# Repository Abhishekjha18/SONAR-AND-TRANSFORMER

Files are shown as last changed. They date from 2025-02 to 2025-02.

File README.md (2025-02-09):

# SONAR-AND-TRANSFORMER
# Transformer & SONAR Project

This repository contains the design, simulation, fabrication, and testing of two analog circuit modules:
- **SONAR Module:** A narrowband ultrasonic Doppler sensor for motion detection.
- **Transformer Module:** Analog transformer circuits incorporating filters and voltage regulators for stable power delivery.

---

## SONAR Module

**Description:**
- Designed, simulated, fabricated, and tested a narrowband ultrasonic Doppler sensor for motion detection.
- Integrated transmitter and receiver circuits with ultrasonic sensors to enable accurate distance measurement.
- PCB layout was executed using **EagleCAD**.

**Key Technologies:**
- **LTSpice** for circuit simulation.
- **EagleCAD** for PCB design.
- Analog circuit design principles for sensor integration.
- **CIRCUITS THAT HELPED IN THE SONAR:**
Screenshot 2025-02-09 at 3 48 58 PM
Screenshot 2025-02-09 at 3 49 10 PM
Screenshot 2025-02-09 at 3 49 34 PM
Screenshot 2025-02-09 at 3 49 40 PM
Screenshot 2025-02-09 at 3 49 48 PM
Screenshot 2025-02-09 at 3 50 22 PM
Screenshot 2025-02-09 at 3 50 44 PM
Screenshot 2025-02-09 at 3 50 54 PM

---

## Transformer Module

**Description:**
- Developed analog transformer circuits that include essential filters and voltage regulators for reliable power delivery.
- Designed, simulated, fabricated, and tested the circuits to ensure stable performance under varying conditions.
- PCB layout was implemented using **KiCad**.

**Key Technologies:**
- **LTSpice** for circuit simulation.
- **KiCad** for PCB design.
- Analog circuit design best practices for power regulation.
- **CIRCUITS THAT HELPED IN THE TRANSFORMER:**
Screenshot 2025-02-09 at 3 33 59 PM
Screenshot 2025-02-09 at 3 34 11 PM
Screenshot 2025-02-09 at 3 34 26 PM
Screenshot 2025-02-09 at 3 34 42 PM
Screenshot 2025-02-09 at 3 34 48 PM
Screenshot 2025-02-09 at 3 34 52 PM
Screenshot 2025-02-09 at 3 35 03 PM

---

## Tools & Technologies

- **LTSpice:** Circuit simulation
- **EagleCAD:** PCB design for the SONAR module
- **KiCad:** PCB design for the Transformer module
- **Analog Circuit Design:** Implementation of filters, voltage regulators, rectifiers and sensor circuits

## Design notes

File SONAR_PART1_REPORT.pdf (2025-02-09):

INDRAPRASTHA INSTITUTE of
INFORMATION TECHNOLOGY
DELHI

### Department

of

### Electronics & Communication Engineering

Circuit Theory and Devices

Dr. Shobha Sundar Ram

### Lab_2: LPF and BPF design in LTSpice

## Student Name: Abhishek Jha Roll No. : 2022023 Date: 18 August 2023

### Objective:

1. Design first, and second order Low Pass and Band Pass filters using RC circuits on the software Ltspice.
2. Plot the magnitude and phase response of the filters in a Bode plot and compare their performances.
2 | Page

Theoretical Calculations:

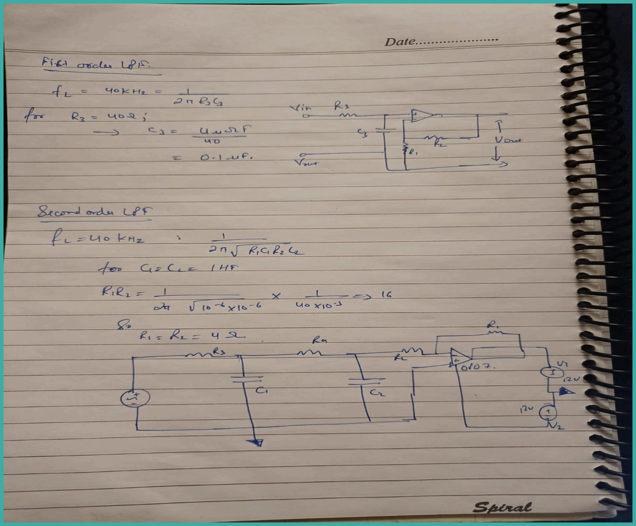
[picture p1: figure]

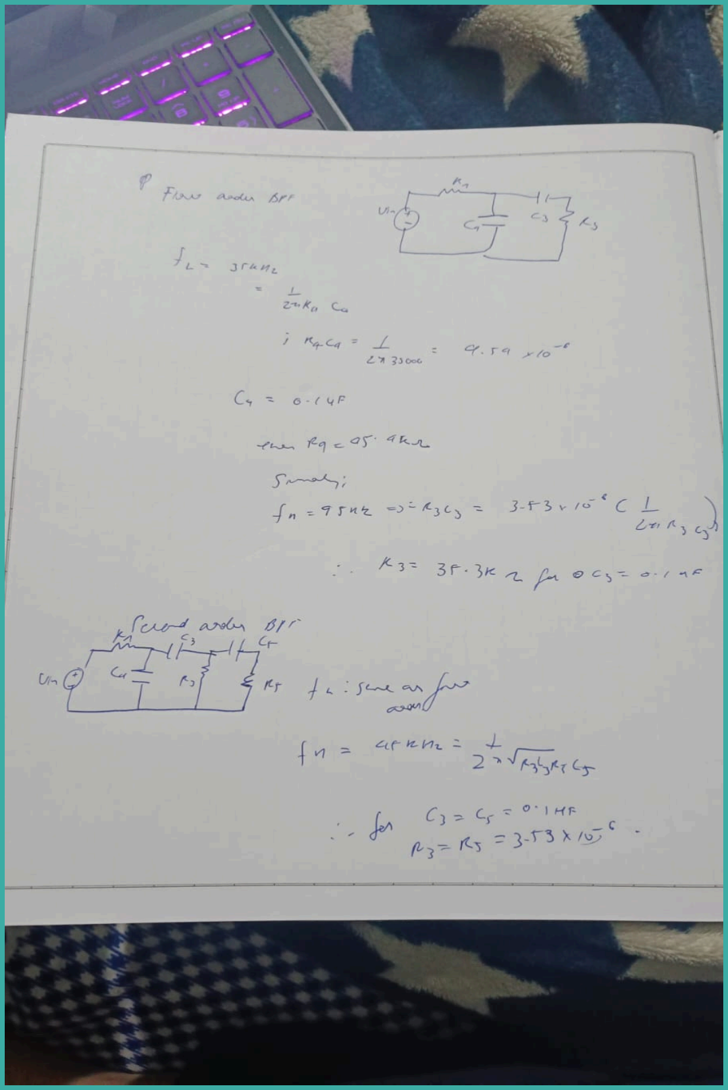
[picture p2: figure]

Observations:

1) LOW PASS FILTER -:
- All signals over a certain frequency are muted in a low pass filter. The signals are attenuated after they reach the cutoff frequency (fH), and after a specific higher frequency, they are entirely suppressed.
- The roll-off rate for the first order LPF is -20 dB/decade, as would be

expected for a single-order filter.
- Except for the fact that the gain will be twice as steep at 40dB/decade as the first order filter, the second order low pass filter's frequency response is identical to that of the first order version.
- The roll-off rate for the second order LPF is -40 dB/decade, as would be expected for a two-order filter. Compared to the first order filter, the change from the passband to the stopband is sharper.

BAND PASS FILTER-:

- The bandwidth for the first order BPF is determined by the lower and upper cutoff frequencies.
- Only signals within the chosen frequency range are permitted to exit the band pass filter; all other signals are blocked.While signals from other frequencies are attenuated, transmissions in the frequency range of fL to fH are allowed to flow through the filter.

- The lower cutoff frequency for the second order BPF is the same as the first order. In comparison to 1st order, the higher cutoff frequency shifts based on the cascaded LPF sections, providing a sharper transition between the passband and stopband.
- A higher order filter offers sharper attenuations beyond the pass band compared to a lower order, with the peak frequency of the first order in a band pass filter being higher than the peak frequency of the second order (the order of a filter is defined by the number of storage elements (capacitors and inductors)).

Plots:

1st order lpf

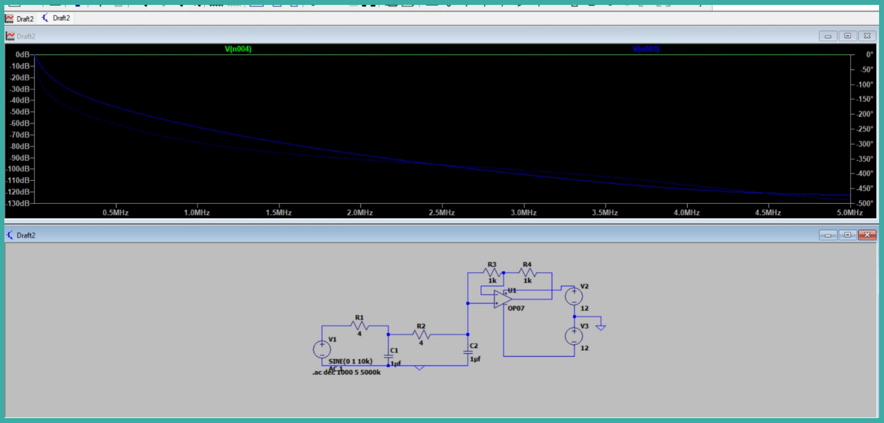
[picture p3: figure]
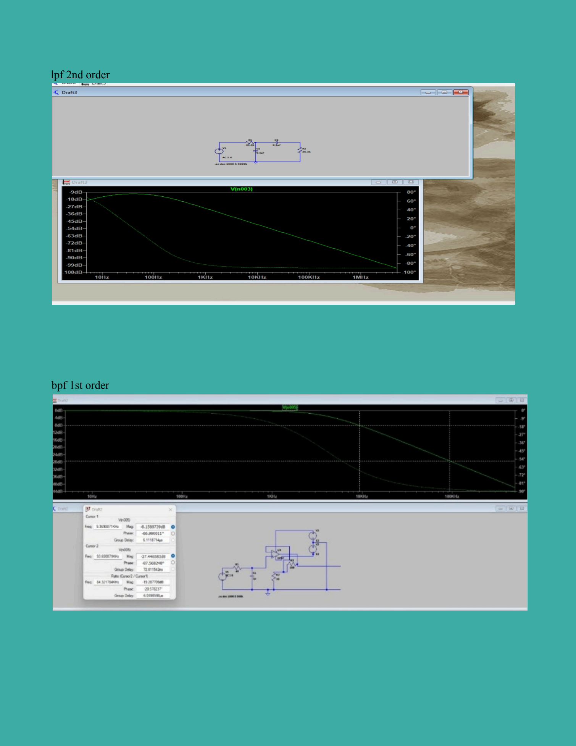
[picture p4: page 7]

lpf 2nd order

bpf 1st order

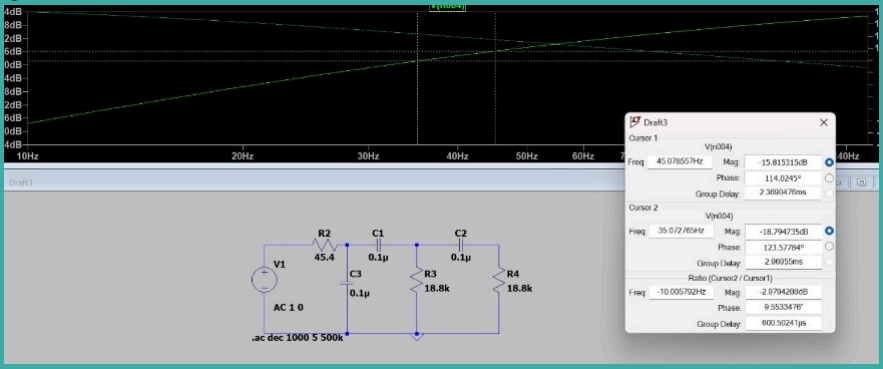
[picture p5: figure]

bpf 2nd order

Conclusions:
An essential device in electronics is a low pass filter, which attenuates higher frequencies while allowing signals below a particular threshold to flow through. It is indispensable in a wide range of applications due to its capacity to filter out undesirable noise and high-frequency components. Low-pass filters are a key element in a world where precise signal handling is necessary.
A frequency selective filter circuit called an active band pass filter is used in electronic systems to distinguish between signals at a single frequency or a range of frequencies that fall within a defined "band" from signals at all other frequencies.This band or frequency range is situated between two corner or cutoff frequencies known as the "lower

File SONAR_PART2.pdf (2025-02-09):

### INDRAPRASTHA INSTITUTE of INFORMATION TECHNOLOGY DELHI

Department
of
Electronics & Communication Engineering

Circuit Theory and Devices

Dr. Shobha Sundar Ram

## Lab 3: Prototype Design of a SONAR Transmitter

Date: 02/09/2023
Submitted by:-
Group 12
Abhishek Jha (2022023)
Mann sharma (2022279)
Mayank Kumar kankheria(2022286)

### OBJECTIVE:

The objective of this lab assignments is to learn how to
a. Read a datasheet for finding out the key information relevant to a design.
b. Develop a prototype of a Sonar transmitter on a breadboard and test its desired outcome.
2 | Page

## Theoretical Calculations:

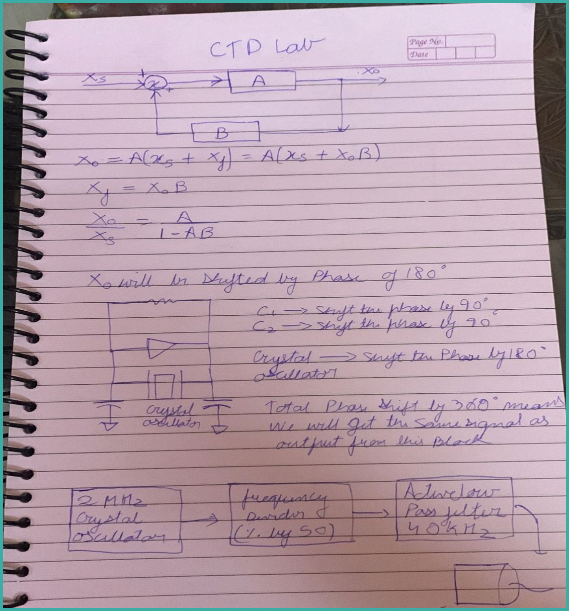
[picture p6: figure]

### Observations:

- FOR TP1-A 2MHz oscillating signal is present at TP1.
- FOR TP2-By using the IC4017 and dividing 2MHz by 10, the oscillating signal at TP2 has a frequency of 200 KHz.
- FOR TP3-By dividing 200 kHz by 5, the oscillating signal at TP3 is at a frequency of 40 kHz. The signal is divided by the frequency divider from 2MHz to 40KHz overall.
An active low pass filter is used to pass the signal from TP3 through. 40KHz is the filter cutoff frequency.
- FOR TP4-The FFT capability of DSO is used to check the frequency information of the signal from TP4; the frequency with the largest peak is at Delta(X)=4us with a span of 1MHz.

## Following are the respective plotsn we got on DSO:-

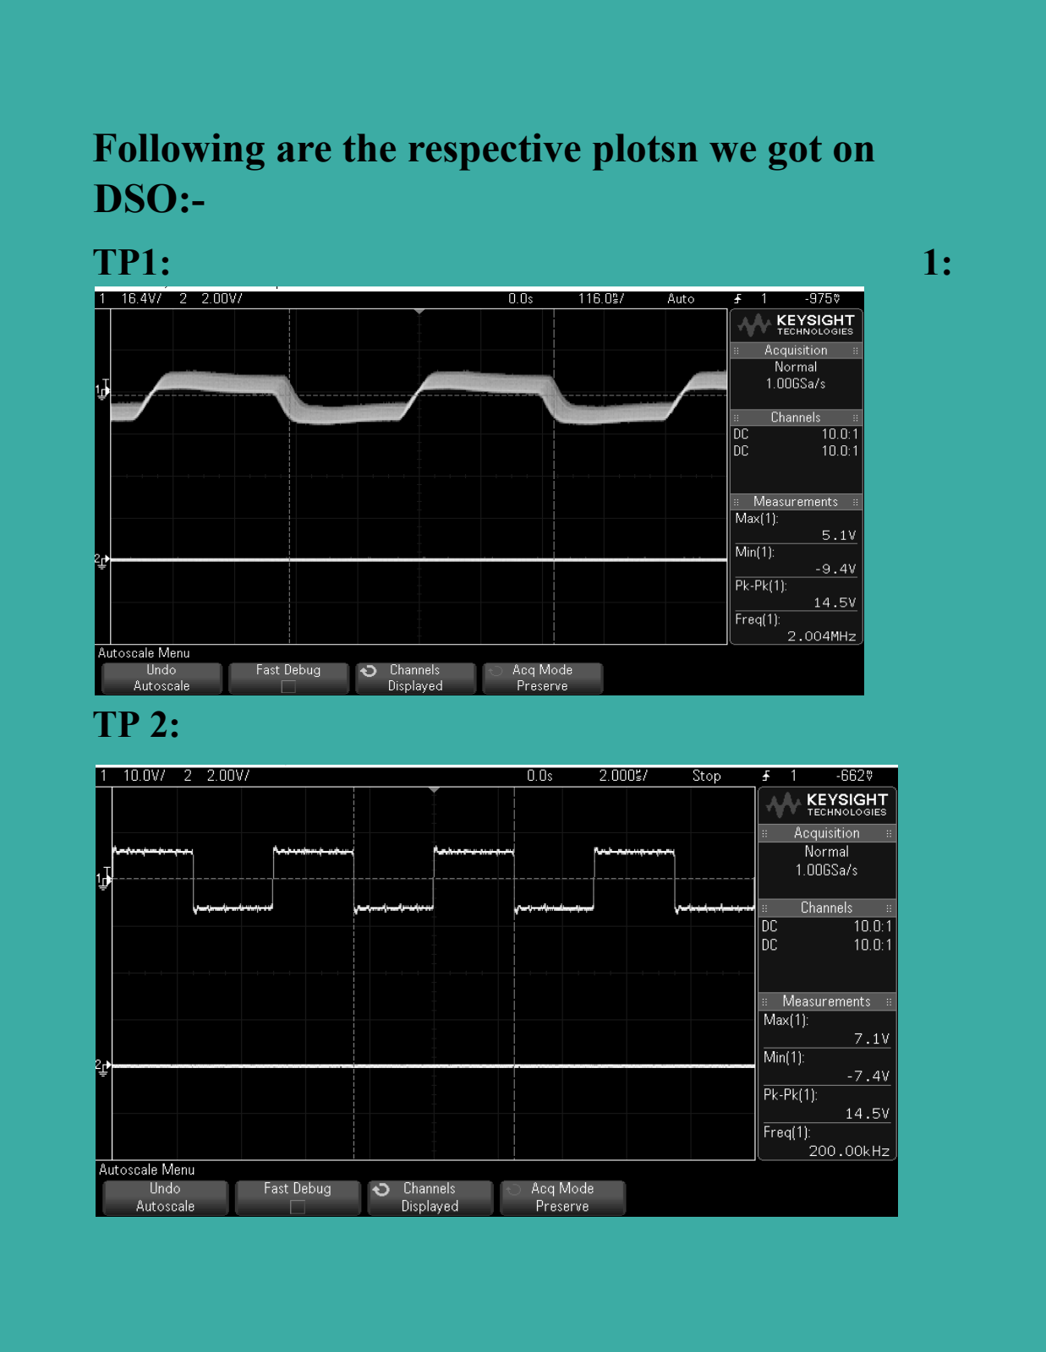
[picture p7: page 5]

TP1: | 1:

TP 2:

TP 3:

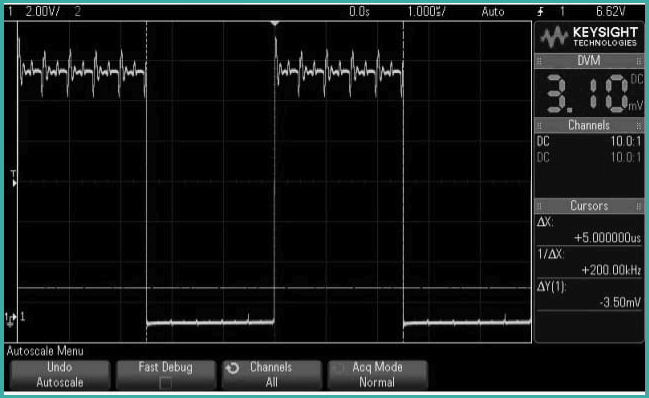
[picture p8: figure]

TP 4:

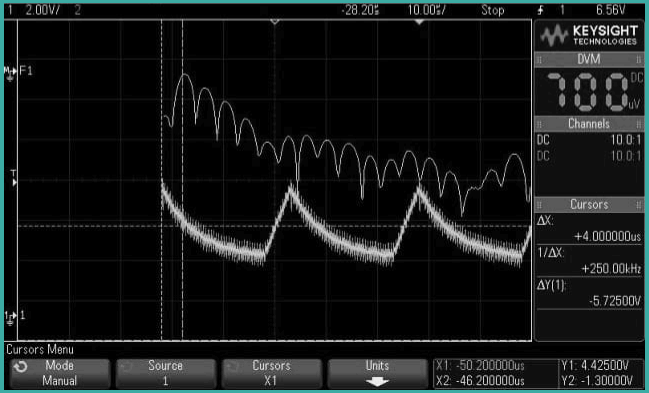
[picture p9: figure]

### Conclusions:

The transmitter utilizes a crystal oscillator to generate a sinusoidal wave with a frequency of 2MHz. This 2MHz input signal is then subjected to a frequency division process, resulting in a 40KHz (f o) output signal achieved by dividing it by a factor of 50. To ensure the elimination of any higher order harmonics, a low pass filter is employed.

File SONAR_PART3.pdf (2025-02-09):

INDRAPRASTHA INSTITUTE of
INFORMATION TECHNOLOGY
DELHI

Department
of
Electronics & Communication Engineering

Circuit Theory and Devices

Dr. Shobha Sundar Ram

## Lab_5: Prototype design of a SONAR receiver

Date: 06/10/2023

### Submitted by:-Group 12 Abhishek Jha (2022023) Mann sharma (2022279) Mayank Kumar kankheria(2022286)

Objective:

a.To develop a prototype of a SONAR receiver on a breadboard and test its desired outcome.
b.With SONAR Tx and Rx, observe the Doppler shift in the received
signal from a moving metal target.

Theoretical Calculations:

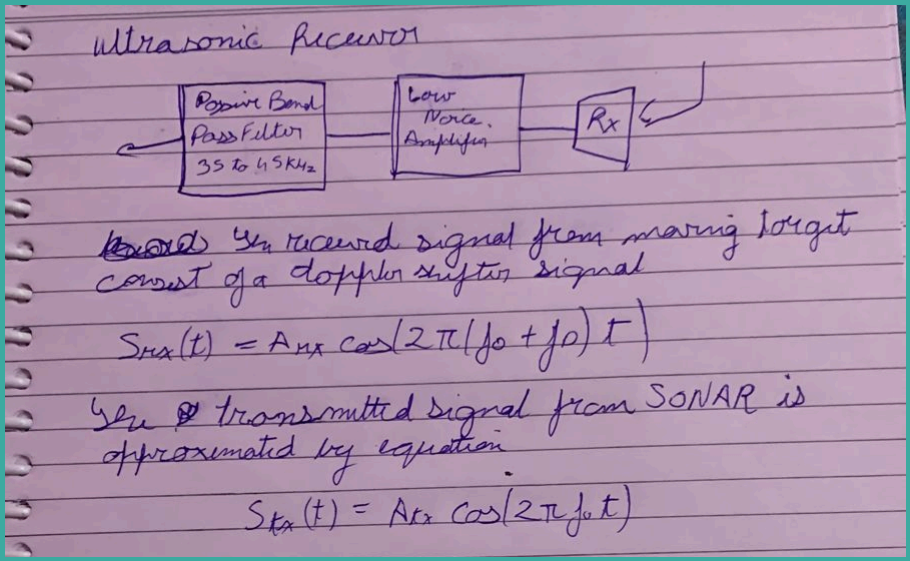
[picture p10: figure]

2 | Page

Observations:

1. The output signal frequency of the LNA at TP1 was detected, which we knew would be somewhat amplified, and the output was observed to be 42Khz at the TP1 point. We created a low noise amplifier and provided 40Khz from the DSO to the LNA.
2. We knew that by passing the output through BPF after that, the frequency would be reduced.
3. We then had our whole receiving circuit.
4. (Lab 3)The transmitter circuit underwent some modifications, the first of which was a shift in the crystal oscillator frequency from 2 Mhz to 4 Mhz. The signal frequency at TP1 was then determined to be 400Khz (4Mhz/10) using IC 4017, and at TP2 it was discovered to be 40Khz (4Mhz/10).
5. Then, a transducer was attached to the transmitter circuit, and its 40 kHz frequency was output.It was passed on the rotating motor and then it was reflected to the receiving transducer of the receiver circuit.
6. The final frequency was observed to be nearly 50Khz.

## Plots:

Transmitter circuit plots:
Signal frequency after division of 400KHz by 10 →

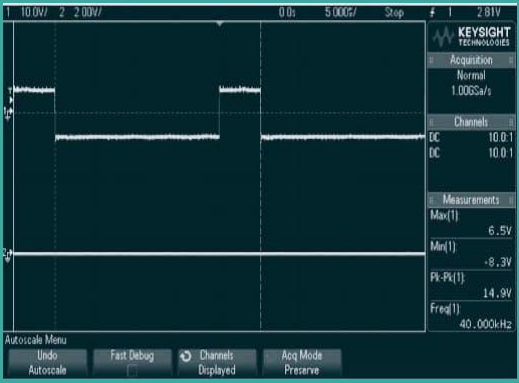
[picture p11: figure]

Signal frequency after passing the signal through the active low pass filter→

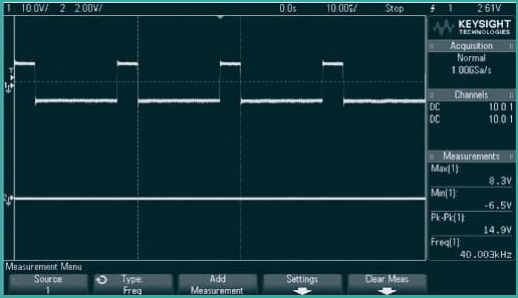
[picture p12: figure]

Conclusions:
1. (Arx <Atx) The transmitted signal is substantially stronger than the received signal. In order to increase the voltage, the signal is therefore sent via a low noise amplifier.
2. To eliminate higher order harmonics and restrict outside interference, band pass filters are used.
3. When a metal target travels ahead of the sonar, the frequency of the received signal should exhibit a Doppler shift starting at 40 KHz since the doppler effect results in a shift equal to 1/r4 the original frequency.

6 | Page

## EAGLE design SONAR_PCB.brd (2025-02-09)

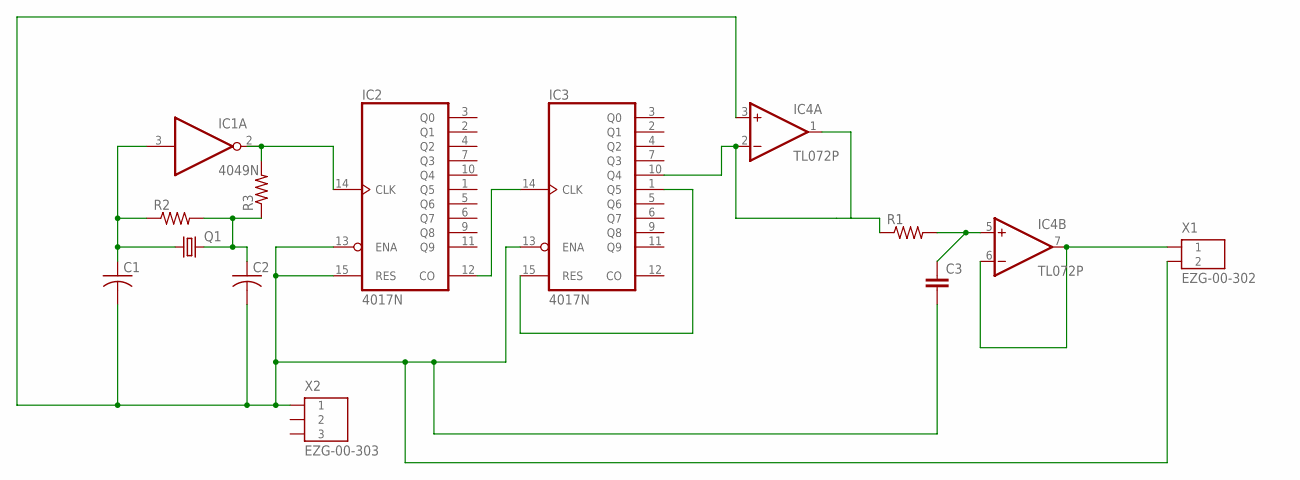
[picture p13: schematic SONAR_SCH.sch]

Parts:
C1, C2: C-US050-025X075; C050-025X075
C3: C2.5/2; C2.5-2
IC1: 4049N; DIL16
IC2, IC3: 4017N; DIL16
IC4: TL072P; DIL08
Q1: CRYSTALHC49U-V; HC49U-V
R1, R2, R3: R-US_0207/10; 0207/10
X1: EZG-00-302
X2: EZG-00-303

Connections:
unnamed: C1.1, IC1.3 (I), Q1.1, R2.1
unnamed: IC1.2 (O), IC2.14 (CLK), R3.2
unnamed: IC2.12 (CO), IC3.14 (CLK)
unnamed: IC3.10 (Q4), IC4.1 (OUT), IC4.2 (-IN), R1.1
unnamed: IC3.1 (Q5), IC3.15 (RES)
unnamed: C3.1, IC4.5 (+IN), R1.2
unnamed: IC4.6 (-IN), IC4.7 (OUT), X1.1
unnamed: C1.2, C2.2, C3.2, IC2.13 (ENA), IC2.15 (RES), IC3.13 (ENA), IC4.3 (+IN), X1.2, X2.1
unnamed: C2.1, Q1.2, R2.2, R3.1
V+: IC4.8 (V+)
V-: IC4.4 (V-)
VDD: IC1.1 (VDD), IC2.16 (VDD), IC3.16 (VDD)
VSS: IC1.8 (VSS), IC2.8 (VSS), IC3.8 (VSS)

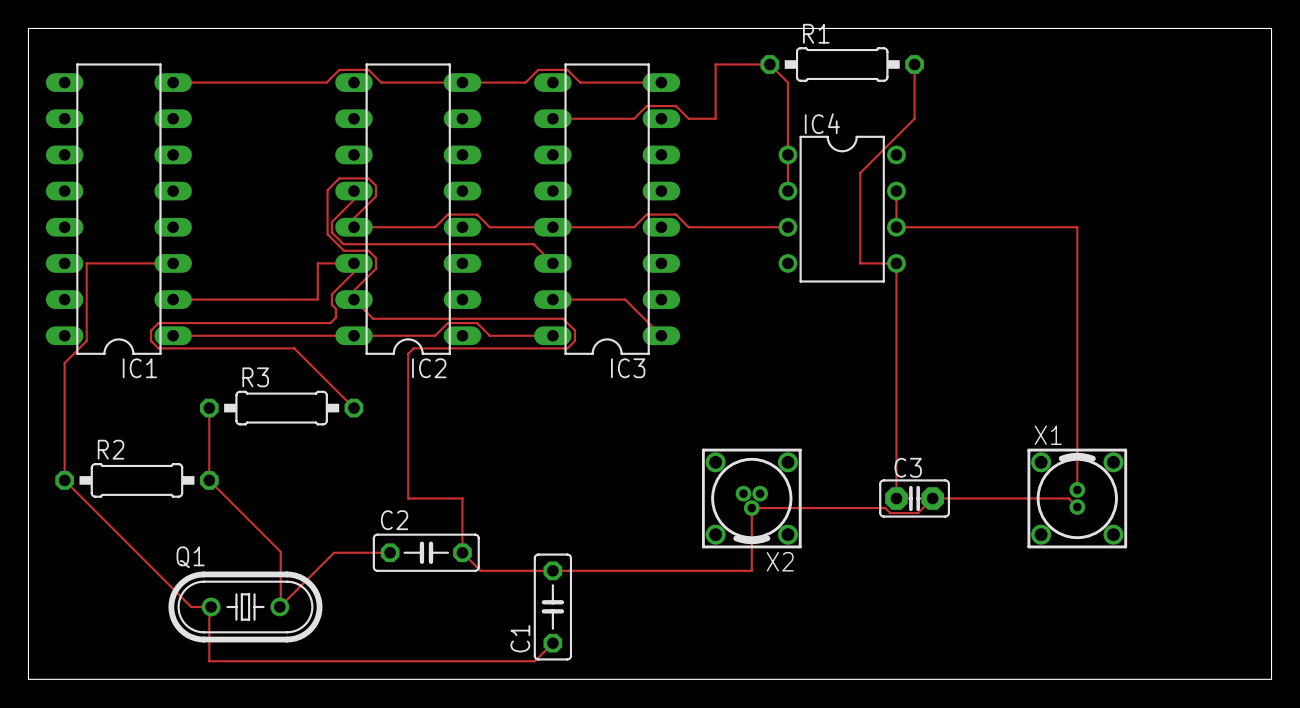
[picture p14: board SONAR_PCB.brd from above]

Board: 2 copper layers, 87.3 x 45.7 mm, 13 parts (0 on the bottom side), 11 nets.

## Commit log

2025-02-09 Add files via upload
    THE CIR FILES OF THE CIRCUITS UTILISED DURING THE TRANSFORMER PROJECT
2025-02-09 Add files via upload
    sonar docs updated
    [SONAR_PCB.brd, SONAR_SCH.sch, SONAR_UPDATEDSCH.sch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]
